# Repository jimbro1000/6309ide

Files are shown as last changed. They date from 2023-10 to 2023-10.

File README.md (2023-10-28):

# 8 Bit IDE for 6309 SBC #

Inspired (and partially copied from) Breadbording Labs 
(https://www.youtube.com/@breadboardinglabs) which is,
in turn, taken from other existing 8 bit IDE projects.

This design is configured to work with my 6309 SBC 
project.

## Status ##

This is a work in progress and is not ready for production.
The two SEL lines are not wired and need some address selection
logic to fit the design to the available mapped memory

## Drivers ##

The IDE operation requires software drivers to simplify
operation. It also needs programming for the GAL

### GAL Definition ###

Input (1-9):  
A0, A4, A5, A6, A6, E, SEL0, RW, SEL1

Output (19-12):  
!UDW, !UDR, !LDW, !IOW, !IOR, !CS0, !CS1, !LDR

ACT = !A5 & !A6 & !A7 & !SEL0

CS0 = !A4 & ACT  
CS1 = A4 & ACT  
IOR = !A0 & ACT & RW  
IOW = A0 & ACT & !RW  
LDR = !A0 & ACT & RW  
LDW = !A0 & ACT & !RW  
UDR = A0 & ACT & RW  
UDW = A0 & ACT & !RW

(note: IOR and LDR are the same)

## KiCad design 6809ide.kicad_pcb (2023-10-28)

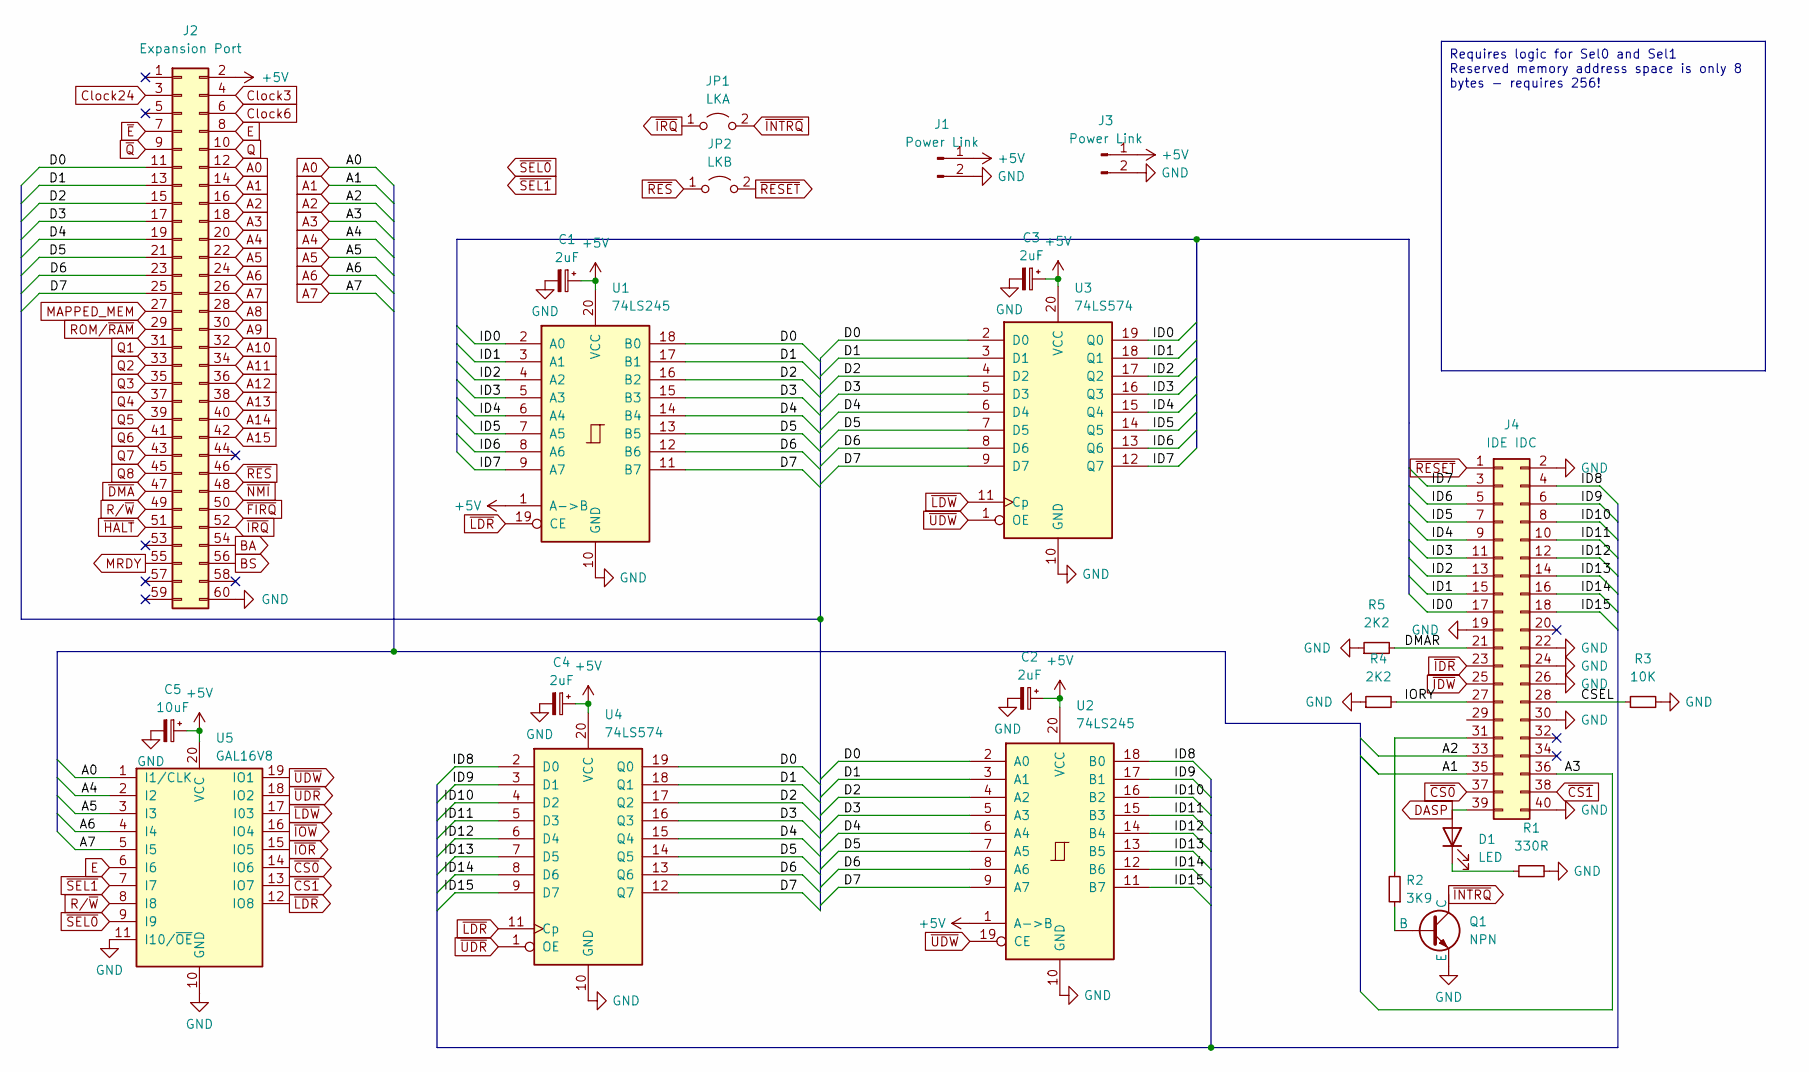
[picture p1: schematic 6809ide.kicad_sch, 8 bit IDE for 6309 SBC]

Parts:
C1, C2, C3, C4: 2uF; CP_Elec_4x3
C5: 10uF; CP_Elec_6.3x3
D1: LED; LED_0805_2012Metric_Pad1.15x1.40mm_HandSolder
J1, J3: Power Link; PinHeader_1x02_P2.54mm_Vertical
J2: Expansion Port; PinHeader_2x30_P2.54mm_Vertical
J4: IDE IDC; IDC-Header_2x20_P2.54mm_Vertical
JP1: LKA; SolderJumper-2_P1.3mm_Open_RoundedPad1.0x1.5mm
JP2: LKB; SolderJumper-2_P1.3mm_Open_RoundedPad1.0x1.5mm
Q1: NPN; SOT-23-3
R1: 330R; R_0805_2012Metric_Pad1.20x1.40mm_HandSolder
R2: 3K9; R_0805_2012Metric_Pad1.20x1.40mm_HandSolder
R3: 10K; R_0805_2012Metric_Pad1.20x1.40mm_HandSolder
R4, R5: 2K2; R_0805_2012Metric_Pad1.20x1.40mm_HandSolder
U1, U2: 74LS245; SOIC-20W_7.5x12.8mm_P1.27mm
U3, U4: 74LS574; SOIC-20W_7.5x12.8mm_P1.27mm
U5: GAL16V8; SOIC-20W_7.5x12.8mm_P1.27mm

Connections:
+5V: C1.1, C2.1, C3.1, C4.1, C5.1, J1.1, J2.2, J3.1, U1.1 (A->B), U1.20 (VCC), U2.1 (A->B), U2.20 (VCC), U3.20 (VCC), U4.20 (VCC), U5.20 (VCC)
/CSEL: J4.28, R3.1
/D0: J2.11, U1.18 (B0), U2.2 (A0), U3.2 (D0), U4.19 (Q0)
/D1: J2.13, U1.17 (B1), U2.3 (A1), U3.3 (D1), U4.18 (Q1)
/D2: J2.15, U1.16 (B2), U2.4 (A2), U3.4 (D2), U4.17 (Q2)
/D3: J2.17, U1.15 (B3), U2.5 (A3), U3.5 (D3), U4.16 (Q3)
/D4: J2.19, U1.14 (B4), U2.6 (A4), U3.6 (D4), U4.15 (Q4)
/D5: J2.21, U1.13 (B5), U2.7 (A5), U3.7 (D5), U4.14 (Q5)
/D6: J2.23, U1.12 (B6), U2.8 (A6), U3.8 (D6), U4.13 (Q6)
/D7: J2.25, U1.11 (B7), U2.9 (A7), U3.9 (D7), U4.12 (Q7)
/DMAR: J4.21, R5.2
/ID0: J4.17, U1.2 (A0), U3.19 (Q0)
/ID1: J4.15, U1.3 (A1), U3.18 (Q1)
/ID2: J4.13, U1.4 (A2), U3.17 (Q2)
/ID3: J4.11, U1.5 (A3), U3.16 (Q3)
/ID4: J4.9, U1.6 (A4), U3.15 (Q4)
/ID5: J4.7, U1.7 (A5), U3.14 (Q5)
/ID6: J4.5, U1.8 (A6), U3.13 (Q6)
/ID7: J4.3, U1.9 (A7), U3.12 (Q7)
/ID8: J4.4, U2.18 (B0), U4.2 (D0)
/ID9: J4.6, U2.17 (B1), U4.3 (D1)
/ID10: J4.8, U2.16 (B2), U4.4 (D2)
/ID11: J4.10, U2.15 (B3), U4.5 (D3)
/ID12: J4.12, U2.14 (B4), U4.6 (D4)
/ID13: J4.14, U2.13 (B5), U4.7 (D5)
/ID14: J4.16, U2.12 (B6), U4.8 (D6)
/ID15: J4.18, U2.11 (B7), U4.9 (D7)
/IORY: J4.27, R4.2
A0: J2.12, U5.1 (I1/CLK)
A1: J2.14, J4.35
A2: J2.16, J4.33
A3: J2.18, J4.36
A4: J2.20, U5.2 (I2)
A5: J2.22, U5.3 (I3)
A6: J2.24, U5.4 (I4)
A7: J2.26, U5.5 (I5)
A8: J2.28
A9: J2.30
A10: J2.32
A11: J2.34
A12: J2.36
A13: J2.38
A14: J2.40
A15: J2.42
BA: J2.54
BS: J2.56
Clock3: J2.4
Clock6: J2.6
Clock24: J2.3
DASP: D1.2 (A), J4.39
E: J2.8, U5.6 (I6)
GND: C1.2, C2.2, C3.2, C4.2, C5.2, J1.2, J2.60, J3.2, J4.2, J4.19, J4.22, J4.24, J4.26, J4.30, J4.40, Q1.3 (E), R1.2, R3.2, R4.1, R5.1, U1.10 (GND), U2.10 (GND), U3.10 (GND), U4.10 (GND), U5.10 (GND), U5.11 (I10/~OE)
MAPPED_MEM: J2.27
MRDY: J2.55
unnamed: D1.1 (K), R1.1
unnamed: J4.31, R2.2
unnamed: Q1.2 (B), R2.1
Q: J2.10
Q1: J2.31
Q2: J2.33
Q3: J2.35
Q4: J2.37
Q5: J2.39
Q6: J2.41
Q7: J2.43
Q8: J2.45
ROM/~RAM: J2.29
R/~W: J2.49, U5.8 (I8)
~CS0: J4.37, U5.14 (IO6)
~CS1: J4.38, U5.13 (IO7)
~DMA: J2.47
~E: J2.7
~FIRQ: J2.50
~HALT: J2.51
~IDR: J4.23
~IDW: J4.25
~INTRQ: JP1.2 (B), Q1.1 (C)
~IOR: U5.15 (IO5)
~IOW: U5.16 (IO4)
~IRQ: J2.52, JP1.1 (A)
~LDR: U1.19 (CE), U4.11 (Cp), U5.12 (IO8)
~LDW: U3.11 (Cp), U5.17 (I03)
~NMI: J2.48
~Q: J2.9
~RESET: J4.1, JP2.2 (B)
~RES: J2.46, JP2.1 (A)
~SEL0: U5.9 (I9)
~SEL1: U5.7 (I7)
~UDR: U4.1 (OE), U5.18 (IO2)
~UDW: U2.19 (CE), U3.1 (OE), U5.19 (IO1)

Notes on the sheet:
Requires logic for Sel0 and Sel1 Reserved memory address space is only 8 bytes - requires 256!

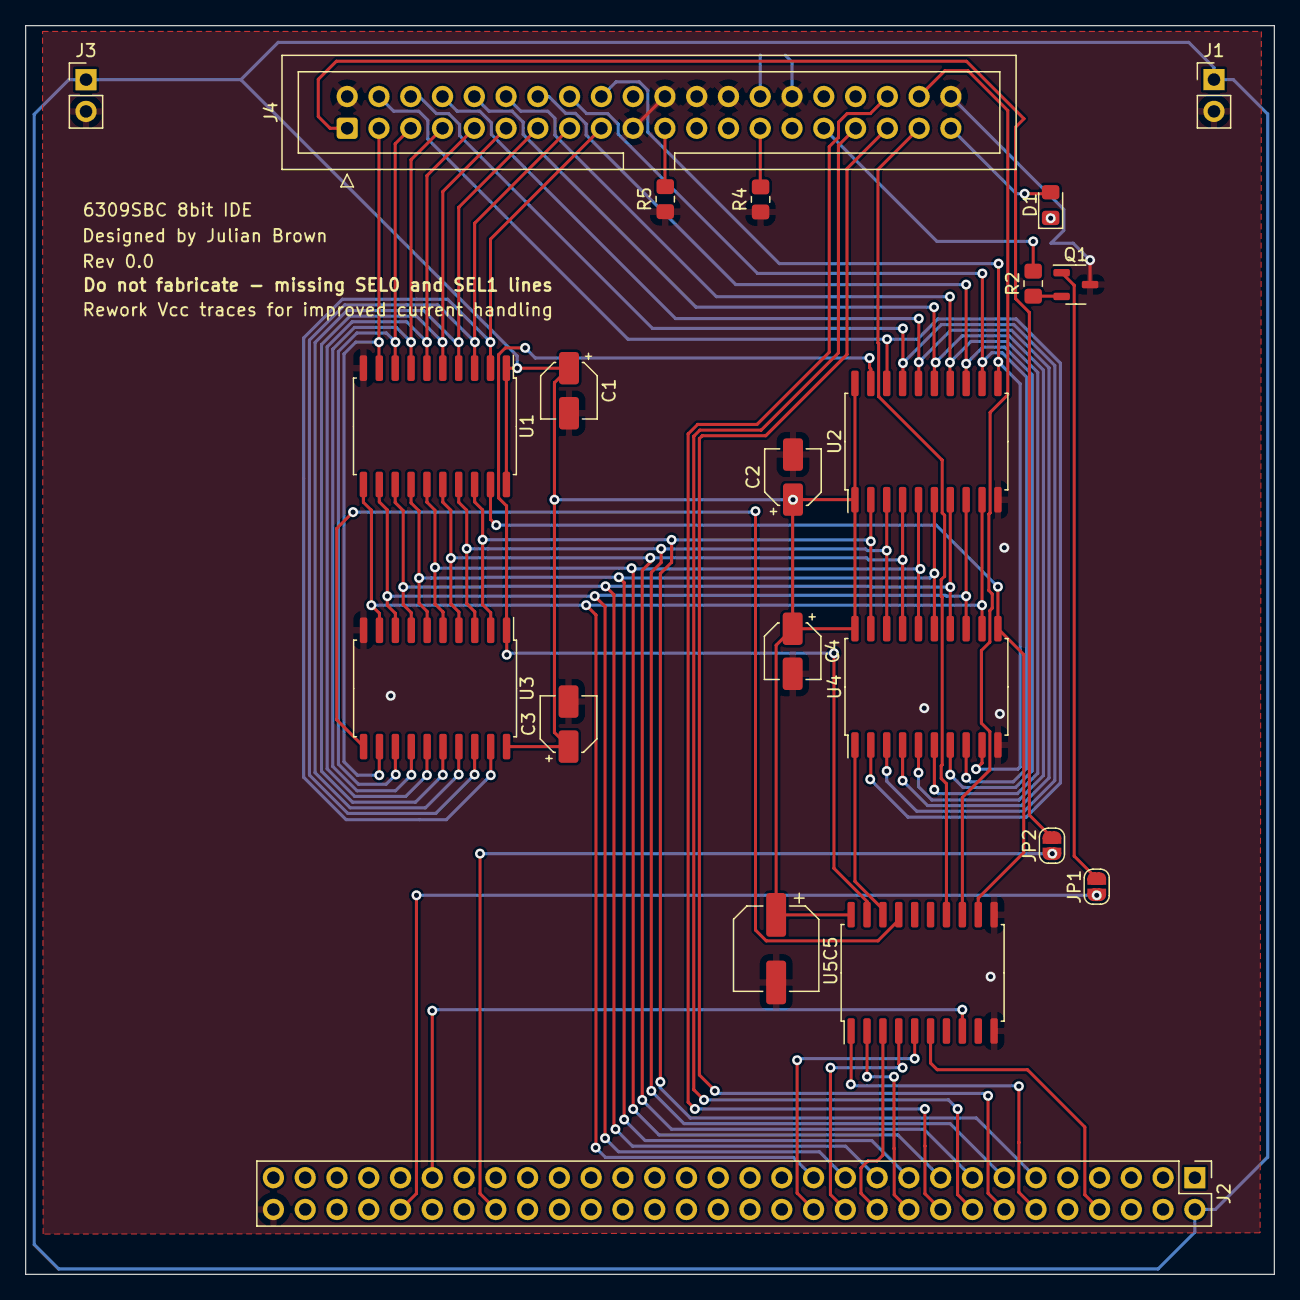
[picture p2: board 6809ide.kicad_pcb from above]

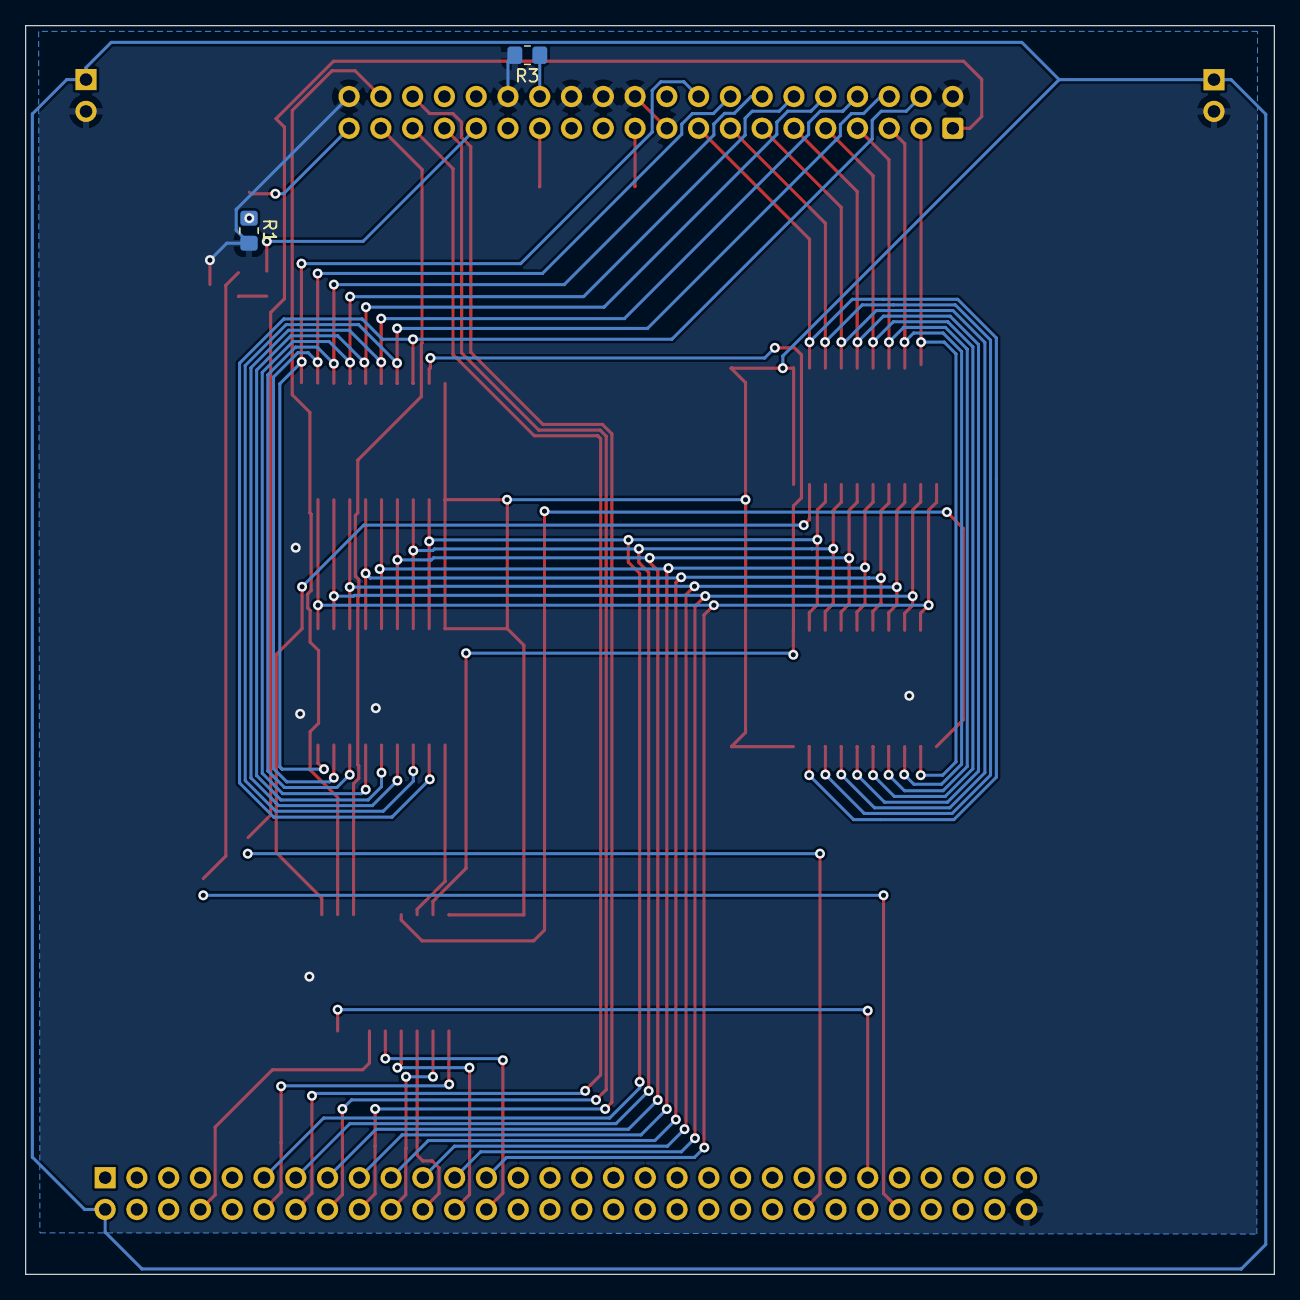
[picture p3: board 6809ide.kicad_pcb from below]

Board: 2 copper layers, 99.8 x 99.8 mm, 23 parts (2 on the bottom side), 53 nets.
